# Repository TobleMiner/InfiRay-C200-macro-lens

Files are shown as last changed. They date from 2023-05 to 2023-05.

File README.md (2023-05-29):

InfiRay C200 magnetic lens mount
================================

The InfiRay C200 aka "Vevor SC240N" or "TopDon TC004" is a high 
framerate thermal imaging camera. From factory the minimum focus distance
is rather large. 

This 3D-printable part allows adding an extra 18mm lens in front of the
camera to reduce minimum focus distance from ~20cm to less than 5cm.  

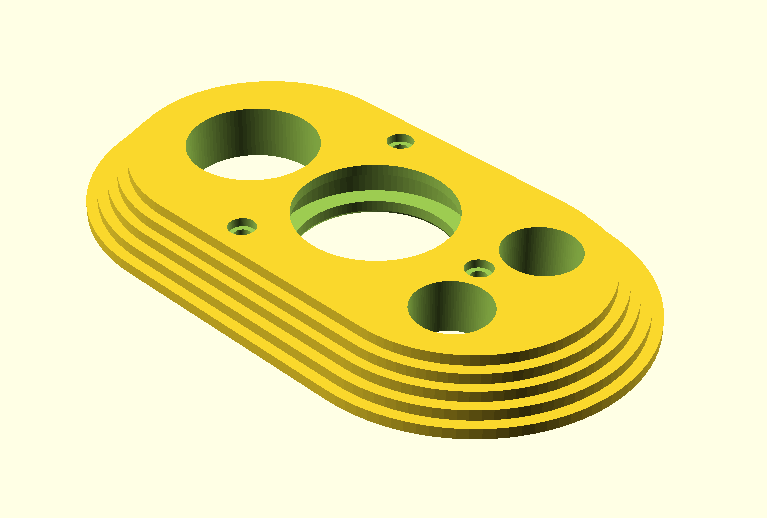
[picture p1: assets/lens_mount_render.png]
Render of the lens mount


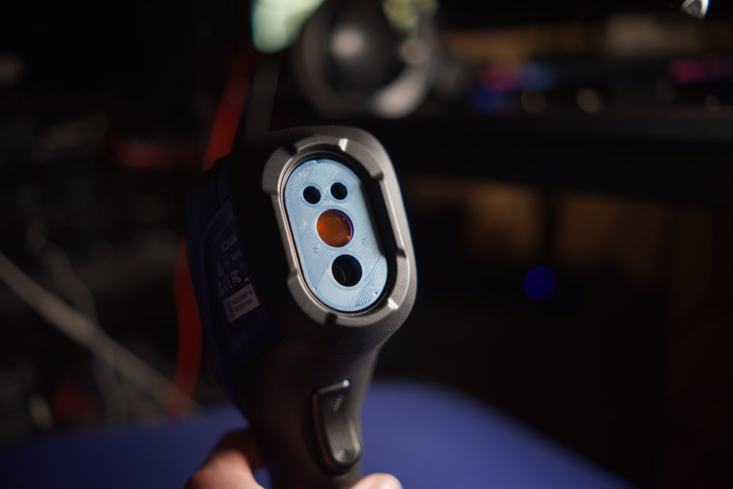
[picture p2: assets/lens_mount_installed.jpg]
Lens mount installed in camera


The lens mount is attached magnetically to the camera body for easy
removal. This requires addition of three small magnets to the interior
of the case.

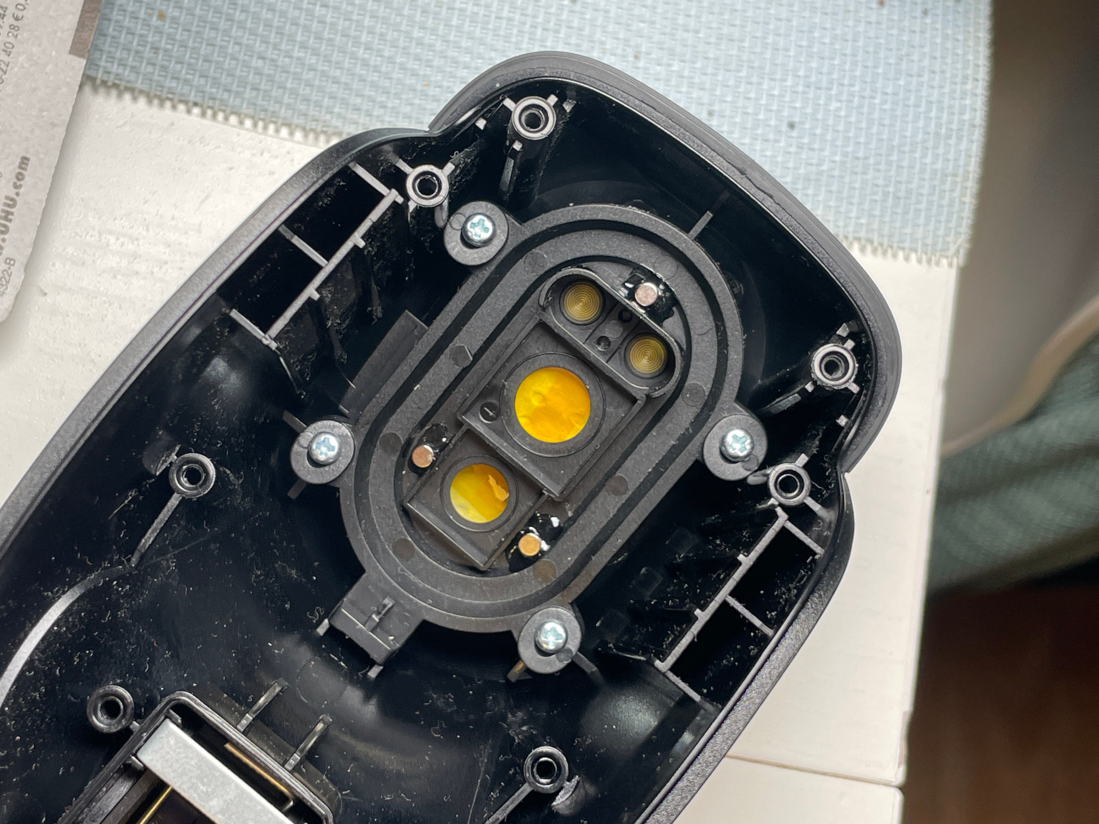
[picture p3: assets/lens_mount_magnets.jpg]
Magnets required for installation in camera


he following types of magnets are required:

4x 3mm⌀*3mm  
2x 3mm⌀*2mm  
1x 5mm⌀*4mm  

The single 5mm⌀*4mm and two of the 3mm⌀*3mm magnet are embedded into the
lens attachment itself. The remaining magnets are glued into the thermal
camera case as illustrated in above photo.

The magnets used need to be rather strong. Grade N45 or higher magnets
have been tested successfully.

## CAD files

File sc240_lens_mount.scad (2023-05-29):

MOUNT_LENGTH = 48.5;
MOUNT_WIDTH = 24.5;
MOUNT_STEPS = 5;
MOUNT_STEP_WIDTH = 2;
MOUNT_STEP_HEIGHT = 1;

STOCK_LENSE_POS_X = 15.5;
STOCK_LENSE_DIAMETER = 14.5;

STOCK_VISIBLE_LIGHT_LENSE_POS_X = 32;
STOCK_VISIBLE_LIGHT_LENSE_DIAMETER = 12;

LENS_HOLE_DIAMETER = 15;
LENS_DIAMETER = 18;
LENS_HEIGHT = 2.8;
LENS_POS_Z = 1;

LED_DISTANCE = 10.8;
LED_DIAMETER = 7;

SCREW_HEAD_SIZE = 2.5; // non-oversized: 2
SCREW_HOLE_SIZE = 1.5; // non-oversized: 1.1
SCREW_THREAD_SIZE = 1; // non-oversized: 0.8

MAGNET_DIAMETER = 5.3; // non-oversized 5
SMALL_MAGNET_DIAMETER = 3.3; // non-oversized 3

BOTTOM = true;
TOP = true;

module rounded_rect(vec) {
    length = vec[0];
    width = vec[1];
    height = vec[2];
    cylinder(height, width/2, width/2, $fn=100);
    translate([0, -width/2, 0]) cube([length - width, width, height]);
    translate([length - width, 0, 0]) cylinder(height, width/2, width/2, $fn=100);
}

module lens_mount_step(rank, length, width, height) {
        translate([MOUNT_WIDTH/2, 0, rank * MOUNT_STEP_HEIGHT]) rounded_rect([length, width, height]);
}

module lens_mount_steps(start, end, undersize=0) {
    for (step = [ start : end - 1]) {
        lens_mount_step(step - start, MOUNT_LENGTH + MOUNT_STEP_WIDTH * step - undersize, MOUNT_WIDTH + MOUNT_STEP_WIDTH * step - undersize, MOUNT_STEP_HEIGHT);
    }
}

module screw_thread() {
    cylinder(2.8, SCREW_THREAD_SIZE/2, SCREW_THREAD_SIZE/2, $fn=100);
}

module screw_hole() {
    cylinder(0.8, SCREW_HEAD_SIZE/2, SCREW_HEAD_SIZE/2, $fn=100);
    translate([0, 0, 0.8]) cylinder(100, SCREW_HOLE_SIZE/2, SCREW_HOLE_SIZE/2, $fn=100);
}

module lens_mount_top_bottom_features(top) {
    translate([11, 0, 0]) if (top) screw_thread(); else screw_hole();
    translate([29, -9.5, 0]) if (top) screw_thread(); else screw_hole();
    translate([29, 9.5, 0]) if (top) screw_thread(); else screw_hole();
}

module magnet() {
    cylinder(4, MAGNET_DIAMETER/2, MAGNET_DIAMETER/2, $fn=100);
}

module small_magnet() {
    cylinder(3, SMALL_MAGNET_DIAMETER/2, SMALL_MAGNET_DIAMETER/2, $fn=100);
}

module lens_mount_bottom() {
    difference() {
        lens_mount_steps(0, 2);
        lens_mount_top_bottom_features(false);
    }
}

module lens_mount_top() {
    translate([0, 0, 2 * MOUNT_STEP_HEIGHT]) {
        difference() {
            union() {
                // undersize top size slightly to compensate for inaccuracy in screw mount
                lens_mount_steps(2, MOUNT_STEPS, undersize=0.2);
                lens_mount_step(MOUNT_STEPS - 2, MOUNT_LENGTH + MOUNT_STEP_WIDTH * (MOUNT_STEPS - 1), MOUNT_WIDTH + MOUNT_STEP_WIDTH * (MOUNT_STEPS - 1), 0);
            }
            lens_mount_top_bottom_features(true);
        }
    }
}

module lens_mount_shape() {
    if (BOTTOM) lens_mount_bottom();
    if (TOP) lens_mount_top();
    /*
    translate([MOUNT_WIDTH/2, 0, 0]) for (step = [ 0 : MOUNT_STEPS - 1]) {
        translate([0, 0, step * MOUNT_STEP_HEIGHT]) rounded_rect([MOUNT_LENGTH + MOUNT_STEP_WIDTH * step, MOUNT_WIDTH + MOUNT_STEP_WIDTH * step, MOUNT_STEP_HEIGHT]);
    }
    */
}

module led() {
    cylinder(10, LED_DIAMETER/2, LED_DIAMETER/2, $fn=100);
}

module lens_holder() {
    cylinder(10, STOCK_LENSE_DIAMETER/2, STOCK_LENSE_DIAMETER/2, $fn=100);
    translate([0, 0,LENS_POS_Z]) cylinder(LENS_HEIGHT, LENS_DIAMETER/2, LENS_DIAMETER/2, $fn=100);
    translate([0, 0,LENS_POS_Z + LENS_HEIGHT + 1]) cylinder(4, STOCK_LENSE_DIAMETER/2, LENS_DIAMETER/2, $fn=100);
}

module visible_light_lense() {
    cylinder(10, STOCK_VISIBLE_LIGHT_LENSE_DIAMETER/2, STOCK_VISIBLE_LIGHT_LENSE_DIAMETER/2, $fn=100);
}

module lens_mount_features() {
    translate([3, 0, 0.5]) magnet();
    translate([9, -LED_DISTANCE/2, 0]) led();
    translate([9, LED_DISTANCE/2, 0]) led();
    translate([STOCK_LENSE_POS_X + STOCK_LENSE_DIAMETER/2, 0, 0]) lens_holder();
    translate([38, -9, 0.5]) small_magnet();
    translate([38, 9, 0.5]) small_magnet();
    translate([STOCK_VISIBLE_LIGHT_LENSE_POS_X + STOCK_VISIBLE_LIGHT_LENSE_DIAMETER/2, 0, 0]) visible_light_lense();
}

module lens_mount() {
    difference() {
        lens_mount_shape();
        lens_mount_features();
    }
}

lens_mount();

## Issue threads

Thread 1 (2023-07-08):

Type of Lense

neuschs, 2023-07-08:
Hi can you add the specs for the needed lense ?

lukasfischer83, 2023-11-09:
I tried a 18mm MCWlaser CO2 Fokus Lens from Amazon with focal length 2in (50.8mm). The original camera focus is set to almost infinity, so this lens sets the new focus also to around 2in if you place it directly in front of the camera. In hindsight a slightly longer focal length would have been better for my applications, like the 4inch or even 7.5inch found on amazon, since you have to get pretty close to the PCB and the field of fiew is quite limited then. You can identify 0402 components easily with the 2in lens though.
